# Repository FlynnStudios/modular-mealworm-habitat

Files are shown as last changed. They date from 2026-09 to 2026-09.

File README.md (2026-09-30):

# Modular Mealworm Habitat

A 3D-printed drawer system for keeping a small mealworm colony in a compact, expandable setup.

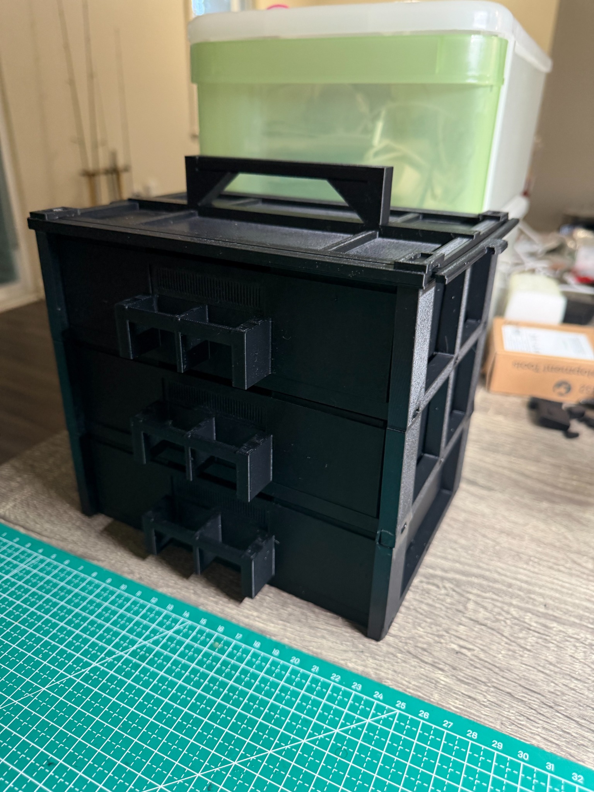
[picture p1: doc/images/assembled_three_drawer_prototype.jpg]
Assembled three-drawer prototype


## Why I Built It

I originally kept mealworms in ordinary food containers. They were convenient, but my ventilation arrangement prevented me from using their stacking features, so the containers occupied more desk space. Their transparent walls also left the insects visible to everyone nearby.

I designed an opaque, three-drawer habitat to separate beetles, small larvae, and larger larvae. Independently removable drawers provide access for routine care, while side vents allow the drawers to remain stacked. Replaceable vent inserts let me revise or replace a failed insert without reprinting the drawer.

## Scope and Status

V1 focuses on a usable basic habitat and a modular frame that can accept additional tiers. Printing time, material use, and structural optimization are planned for later iterations; sensing and automation are longer-term possibilities.

**The three-tier prototype is printed and assembled, and initial use has begun.** Parts were printed in PETG HF on a Bambu P1S with a 0.4 mm nozzle.

- Initial checks confirmed independent drawer access, vent fit, frame assembly, and manual cover installation and removal.
- Occasional drawer realignment remains. Containment, airflow, fourth-tier expansion, loaded carrying, and long-term durability still need verification.

The validation reports distinguish observed results from checks that remain open.

## Repository Guide

| File or folder | Contents |
| --- | --- |
| [Design requirements](design-requirements.md) | Product definition, requirement IDs, and verification criteria. |
| [Development logic](logic.md) | My design workflow and reflections. |
| [Working with AI](thoughts.md) | My experience using AI for test models, design changes, and iteration. |
| [Validation reports](doc/test-logs/) | Test parameters, observations, design decisions, and unresolved checks, linked to requirement IDs. |
| [Build guide](doc/build.md) | File quantities, printing notes, assembly, and the prototype configuration. |
| [CAD source](models/cad/) | Editable OpenSCAD models, organized by component. |
| [Current STL files](models/stl/current/) | Selected drawer, rack, cover, vent, and rear-stop models. |
| [Experimental STL files](models/stl/experiments/) | Fit coupons and earlier variants retained to document iteration. |
| [Photos](doc/images/) | Printed parts, assembly details, and the prototype. |

To review the project, start with the requirements, then the development logic and validation reports. To reproduce the parts, start with the build guide and current STL files.

## Authorship and License

I developed and tested this project with AI assistance for CAD generation and documentation. Requirements, design decisions, and physical evaluation were guided by my own use and observations.

A license has not yet been selected.

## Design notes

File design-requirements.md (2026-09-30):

# V1 Product Requirements

My goal for V1 is a compact, opaque, modular habitat for a small mealworm colony. The starting point is three independent drawers for beetles, small larvae, and larger larvae, with roles reassigned as the colony develops. The system must support routine care and later tier expansion.

V1 prioritizes usable functionality and reliable assembly. Print-time and material optimization, sensing, and automation are reserved for later development.

This document defines design inputs and planned verification. Detailed geometry, connection types, manufacturing settings, and test results are recorded separately.

## 1. Requirement Index

| ID | Requirement | User need | V1 target | Verification |
| --- | --- | --- | --- | --- |
| REQ-01 | Independent drawer access | Manage life stages and perform routine care separately | Three compartments; access one without removing the others | Operation demonstration |
| REQ-02 | Compact desktop footprint | Reduce the space occupied by separately arranged containers | Less occupied desktop area than the existing three-container setup | Dimensional comparison |
| REQ-03 | Ventilation and serviceability | Maintain ventilation when stacked; replace ventilation components independently | Open ventilation paths during closed use; replacement without replacing the drawer | Inspection and replacement trial |
| REQ-04 | Occupant containment | Keep larvae and beetles in their assigned compartments | No escape or transfer between drawers during the defined observation period | Containment observation |
| REQ-05 | Tier expansion | Increase capacity as the colony grows | Add one tier while reusing existing tiers; retain stability and access | Expansion assembly and load test |
| REQ-06 | Removable top cover and carrying handle | Access the upper tier and move the assembled system | Hand-removable cover; secure handling of the loaded three-tier assembly | Removal and carrying tests |
| REQ-07 | Rearward drawer retention | Prevent a drawer from being pushed out of the rear | A seated drawer remains supported during normal insertion | Repeated insertion test |
| REQ-08 | Drawer support and alignment | Insert and withdraw drawers without slipping or jamming | Supported, aligned travel without manual sideways correction | Loaded operation test |
| REQ-09 | Fabrication with available equipment | Build the system using existing printing equipment | Printable components and assembly without specialized equipment | Slicing review and prototype build |

All nine requirements are within V1 scope. IDs provide stable references; their sequence does not indicate implementation order. Verification results are tracked in the test records.

## 2. Requirement Definitions and Checks

### REQ-01 — Independent drawer access

**Requirement:** The system shall provide three separate rearing compartments. Each drawer shall be removable and reinsertable for feeding, inspection, transfer, and cleaning while the other drawers remain installed.

**Verification:** Demonstrate each operation on every tier. Confirm that access does not require dismantling the rack or removing another drawer.

### REQ-02 — Compact desktop footprint

**Requirement:** In its normal closed configuration, the system shall occupy less desktop area than the existing three containers arranged separately for use.

**Verification:** Compare occupied areas using a consistent measurement boundary and ventilation clearance. Record temporary drawer-access space separately.

### REQ-03 — Ventilation and serviceability

**Requirement:** Each compartment shall have a ventilation path available with all drawers closed and stacked. Ventilation components shall be replaceable without replacing or damaging the drawer body.

**Verification:** Inspect every tier for obstructed openings and repeat component replacement. Confirm secure retention and absence of damage. Opening inspection establishes the availability of a ventilation path; suitability during rearing remains part of the use evaluation.

### REQ-04 — Occupant containment

**Requirement:** The closed system shall retain the intended larvae and beetles within their assigned drawers, including the smallest larvae intended for this system.

**Verification:** Observe a populated assembly inside a secondary enclosure. Record life stages, approximate sizes, conditions, and duration. Acceptance requires no escape or unintended movement between compartments within that test period.

### REQ-05 — Tier expansion

**Requirement:** The system shall accept at least one additional tier without remaking the existing tiers. The expanded assembly shall remain stable under its intended load and preserve independent drawer access.

**Verification:** Assemble a fourth tier, apply a recorded representative load, and operate each drawer. Check for connection separation, instability, interference, and damage. This test establishes four-tier capability only.

### REQ-06 — Removable top cover and carrying handle

**Requirement:** The top cover shall remain secured during routine operation and be removable by hand for access and expansion. Its handle and attachment shall support moving the three-tier assembly at its defined service load.

**Verification:** Repeat cover installation and removal, then perform a controlled carrying test using an inert load representing the intended filled assembly. Acceptance requires no release, cracking, or permanent deformation that impairs function. Expanded-stack carrying requires a separate load case.

### REQ-07 — Rearward drawer retention

**Requirement:** Normal insertion shall not push a drawer beyond its supported rear position or allow it to exit through the back of the rack.

**Verification:** Repeatedly seat each loaded drawer and inspect its final position and support. Confirm that rearward travel control remains effective without prescribing a particular stopping mechanism.

### REQ-08 — Drawer support and alignment

**Requirement:** Each drawer shall remain supported and aligned throughout normal insertion and withdrawal, until intentionally removed. It shall not slip sideways or jam in a way that requires manual realignment.

**Verification:** Operate loaded drawers on every tier. Record sideways displacement, jams, manual corrections, and visible damage. Acceptance requires completion of the defined cycles without these functional failures.

### REQ-09 — Fabrication with available equipment

**Requirement:** Custom components shall be printable on the available Bambu P1S with a 0.4 mm nozzle and assemblable without specialized equipment. V1 shall establish a reproducible build process; no fixed print-time or material-mass limit is assigned.

**Verification:** Review build-volume fit, print the components, and assemble the system. Record material, settings, orientation, supports, finishing, and assembly steps. Record time and material use as a baseline, distinguishing slicer estimates from measurements.

## 3. Test Log Plan

Dedicated logs cover tests that require repeated operation, load testing, biological observation, or comparison across revisions. Requirements sharing a setup are recorded together.

| Planned log | Related requirements | Record focus |
| --- | --- | --- |
| Ventilation and component replacement | REQ-03, REQ-09 | Opening availability, replacement cycles, retention, damage, and relevant print conditions |
| Occupant containment | REQ-04 | Life stages, sizes, escape paths, observation conditions, duration, and outcome |
| Modular assembly and expansion | REQ-05 | Assembly method, connection behavior, load, stability, and drawer access after expansion |
| Top cover and carrying handle | REQ-06 | Removal cycles, retention, total carried mass, lifting method, and structural condition |
| Drawer operation and retention | REQ-01, REQ-07, REQ-08 | Independent access, support, alignment, rearward travel, and operating failures |

REQ-02 is recorded as a short footprint comparison in the assembly record. REQ-09 is covered by a complete build record and the relevant component trials; it does not require a duplicate standalone test report.

Each log identifies the REQs, tested revision, setup, acceptance criteria, results, evidence, and follow-up action. Cycle counts, service loads, and observation durations remain open test-planning parameters here and are fixed in the relevant protocol before testing. These planned checks do not indicate that a requirement has passed.

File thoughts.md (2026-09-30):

# My Experience Working with AI

In this project, I wanted to build a mealworm habitat and see how far I could go with AI-assisted design. During development, I realized that some changes would be faster to make myself. I still continued with AI because I wanted to understand where it worked well and where it needed more guidance.

## What Worked Well

AI was useful for generating small test models with different parameters. For example, before printing the full frame, I could print several connection samples and compare their fit. This helped me find problems before spending more time and material on larger parts.

I also think AI can help people who have less experience with testing and version management. It suggested testing individual features, keeping previous versions, and recording the results. It could quickly provide several options for comparison, but I still needed to print and test them to decide which one worked.

## What Took More Time Than Expected

The C connection was one example. After testing its fit, I expected AI to keep the confirmed dimensions and use that connection as the basis for the frame and tier connections. I understood that a different application might need another check, but the result we already had should not be lost.

However, AI sometimes introduced a different arrangement or added separate locking pieces. My intention was to put the pegs directly on the crossbars and the sockets in the side frames. At the same time, I was considering how to assemble the parts and place them on the print bed. AI did not consistently include all of these points without further instructions.

I had to explain the same requirements several times. Clearer prompts helped, but part of the conversation was only correcting its understanding. This used extra time and tokens, and it was especially frustrating when usage was limited.

Once I knew exactly what needed to change, directly editing the CAD model was faster than explaining it again and checking whether AI had changed anything else. I noticed this during the project, particularly for small changes to details that had already been tested.

## What I Would Change Next Time

I would still use AI for initial ideas and test models with different parameters. For integration and small CAD changes, I would do more of the work directly once the design was clear.

I would also try giving AI a short record of confirmed dimensions, tested connections, and what could be changed. I want to see whether this reduces repeated explanations.

This is my experience from one project. I would need to try other models, platforms, and tools before making a broader judgment. I also have not tested whether a higher subscription level would solve these problems.

---

**Reflection recorded:** 2026-09-30 EDT (UTC-04:00).

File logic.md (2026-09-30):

# Product Development Logic

My process starts with a practical need. I define the product, carry out desk research, and work through the requirements with small prototypes and repeated tests.

## Development Process

```mermaid
flowchart TD
    A["Product definition and desk research"] --> B["Requirements and REQ IDs"]
    B --> C["Design and trade-offs"]
    C --> D["Minimum viable prototype"]
    D --> E["Testing and records"]
    E -->|"Iterate"| C
    E -->|"Pass"| F["Assembly and functional testing"]
    F -->|"Iterate"| C
    F -->|"Pass"| G["Complete V1.0"]
```

1. **Product definition and desk research.** I start with the problem I want to solve, look into existing approaches, and decide what the first version needs to do.

2. **Requirements and numbering.** I turn the product goals into requirements, assign REQ IDs, and define how to check them. The IDs connect related work; they do not determine the order of development.

3. **Design and trade-offs.** I compare possible solutions and consider what each adds in function, complexity, time, and cost before choosing an approach.

4. **Minimum viable prototyping.** I test key features before committing to a complete model. Each prototype answers a specific question and helps me decide the next step.

5. **Testing and iteration.** I record observations, data, and photos, modify the design, and test again. I update the records after each round. Assembly and functional testing check whether the parts work together and meet the requirements.

## Post-design Reflection

> [!NOTE]
> **What I want to improve next time**
>
> - **Set clearer test criteria.** I want to decide what counts as a pass before comparing designs.
> - **Check shared dimensions earlier.** I will check how each change affects the parts around it.
> - **Plan assembly checks.** I will make checking one assembled module a regular step before printing more copies.
> - **Give each revision a clear purpose.** I will state what I expect a change to improve, then check whether it does.
> - **Know when to stop.** I will finish the required functions for the current version and leave optional improvements for the next one.

**Reflection recorded:** 2026-09-20 14:31 EDT. **Revised:** 2026-09-29 23:47 EDT (UTC-04:00).

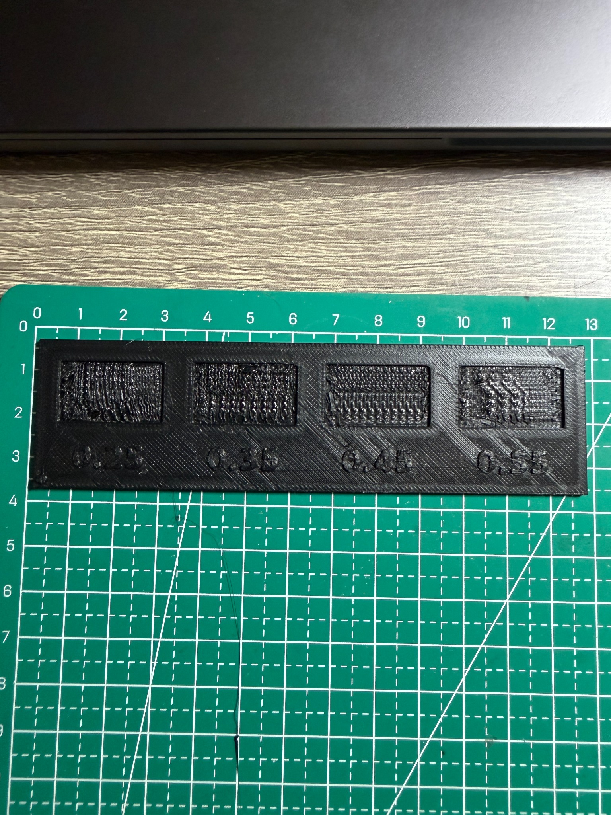
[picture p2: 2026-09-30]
doc/images/vent_coupon_top.jpg

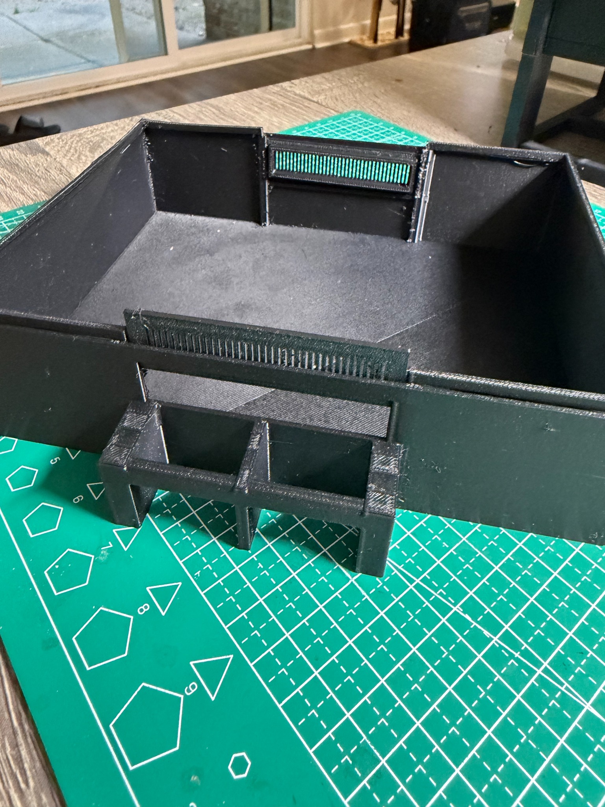
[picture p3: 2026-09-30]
doc/images/drawer_vent_fit.jpg

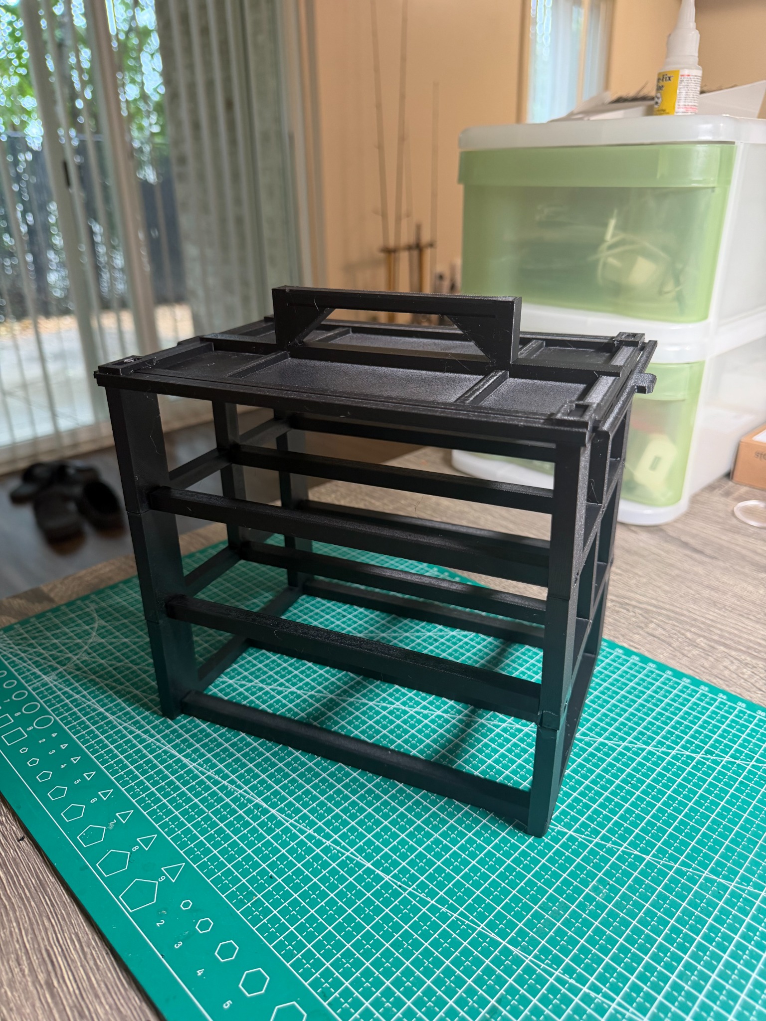
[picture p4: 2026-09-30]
doc/images/empty_three_tier_rack.jpg

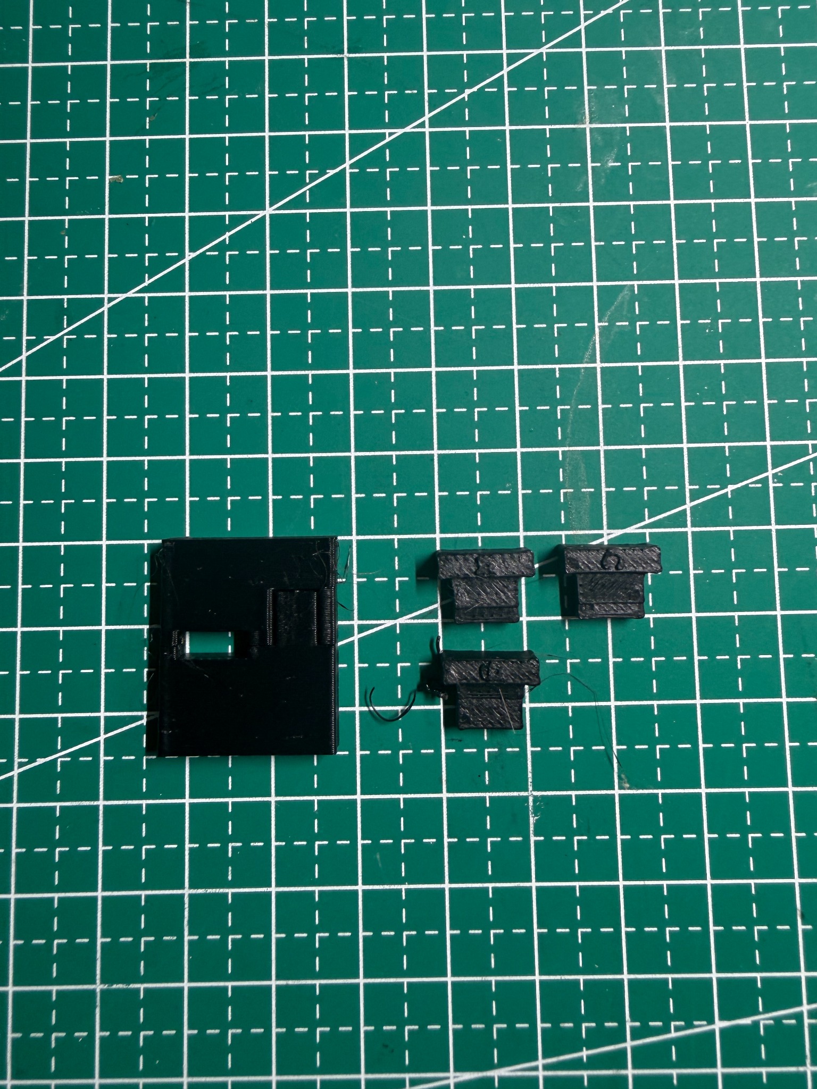
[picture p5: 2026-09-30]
doc/images/joint_fit_coupon.jpg

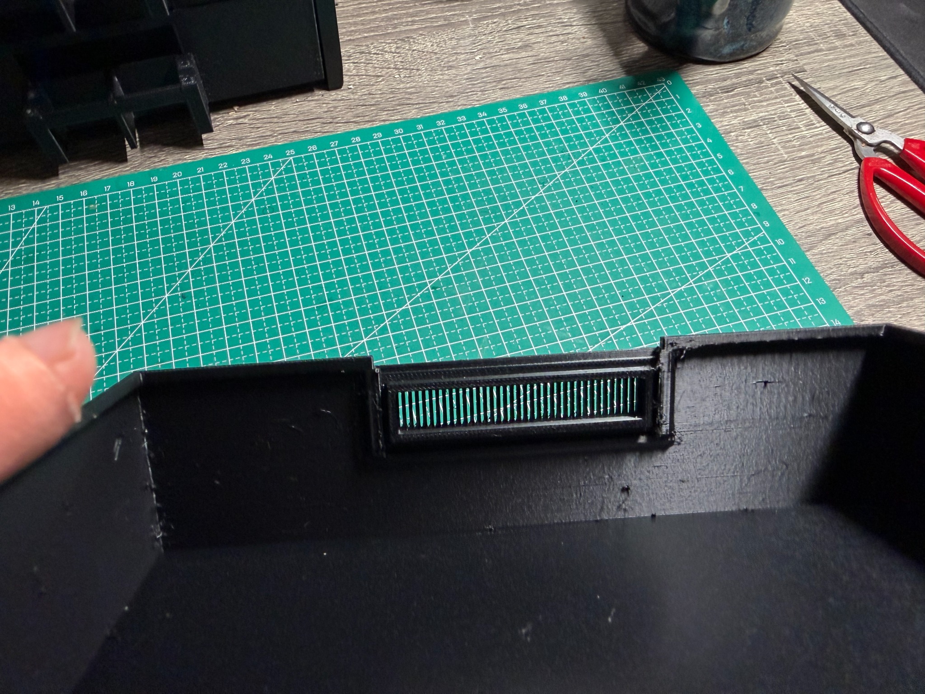
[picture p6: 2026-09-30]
doc/images/vent_receiver_closeup.jpg

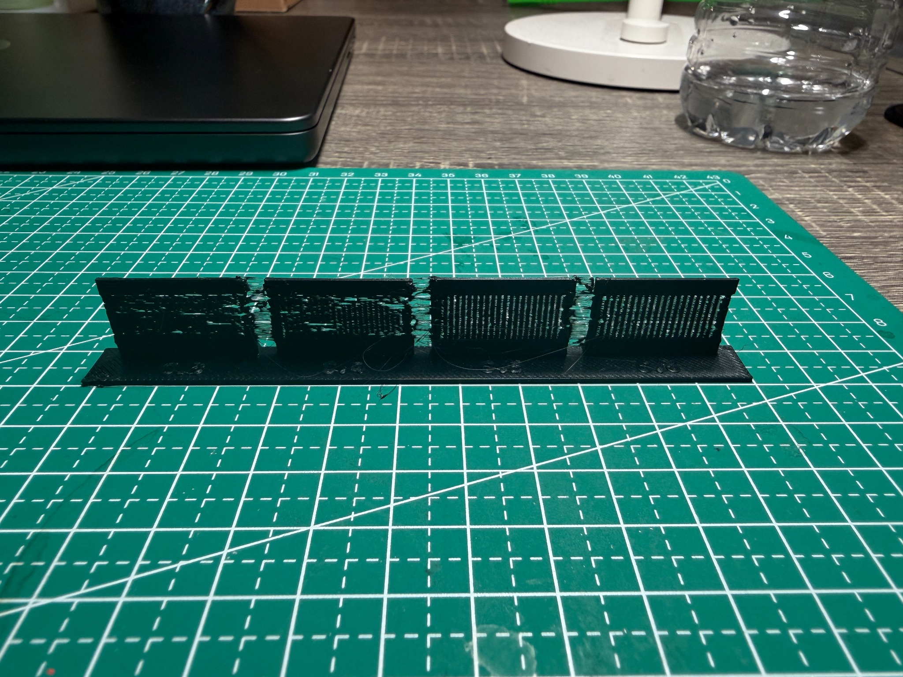
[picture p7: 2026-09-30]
doc/images/vent_coupon_oblique.jpg

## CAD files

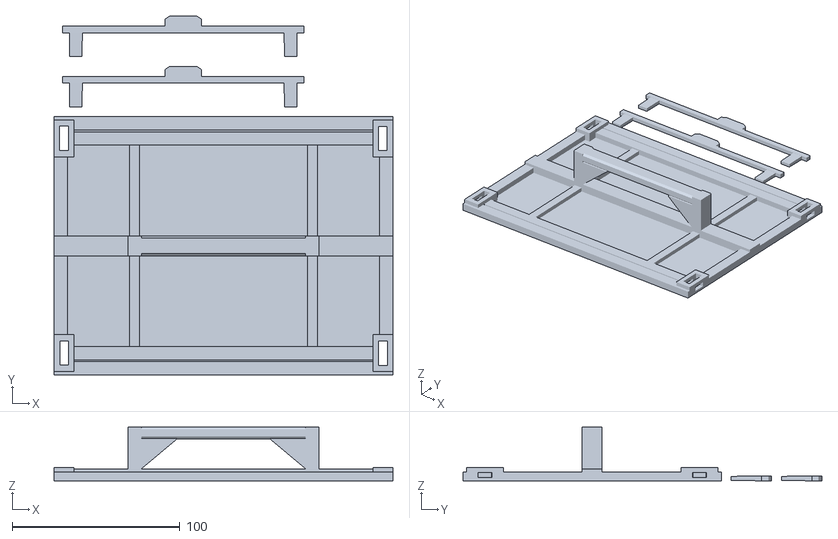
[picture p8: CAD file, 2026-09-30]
models/stl/current/top_cover_carry_v1_1_complete_plate.stl
202.0 x 214.0 x 32.0

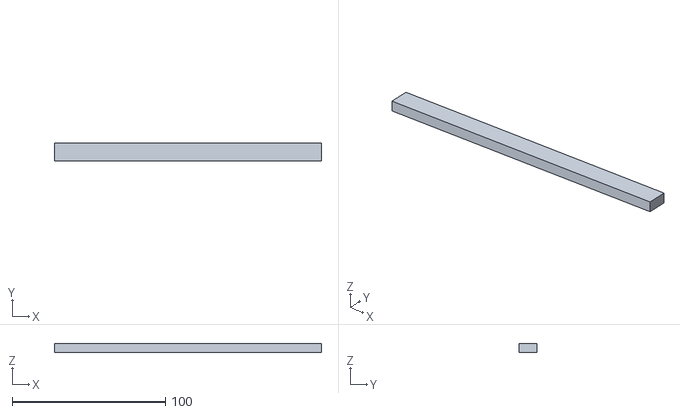
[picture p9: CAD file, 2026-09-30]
models/stl/current/rear_center_glue_stop_r3_5_174x12x6.stl
174.0 x 12.0 x 6.00

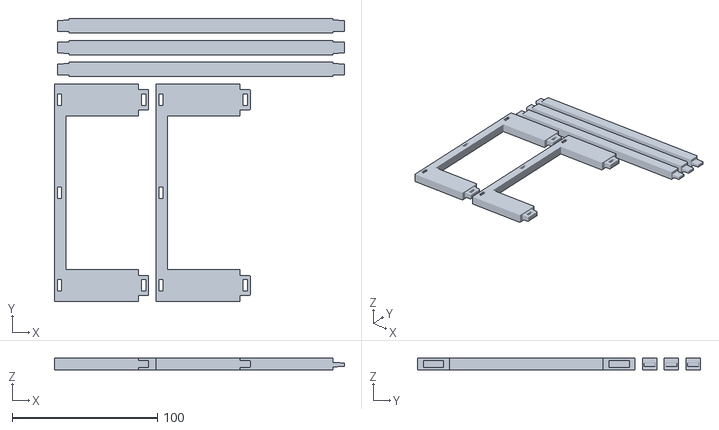
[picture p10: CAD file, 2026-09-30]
models/stl/experiments/rack_flatpack_beam_locked_stack_r3_4_plate.stl
200.0 x 195.0 x 8.00

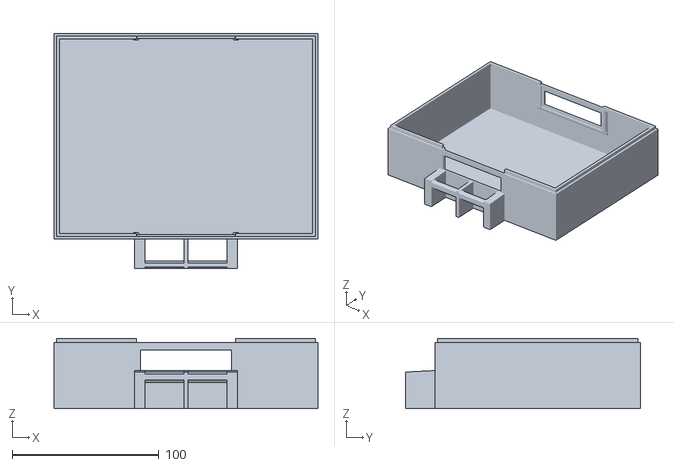
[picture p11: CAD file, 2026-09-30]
models/stl/current/single_drawer_body_v1_4.stl
180.0 x 160.0 x 48.0

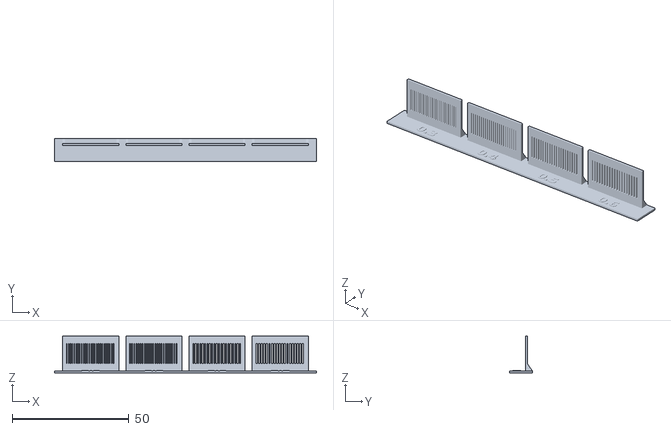
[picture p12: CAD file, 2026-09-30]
models/stl/experiments/vent_slot_calibration_v2_binary.stl
112.0 x 10.0 x 15.8

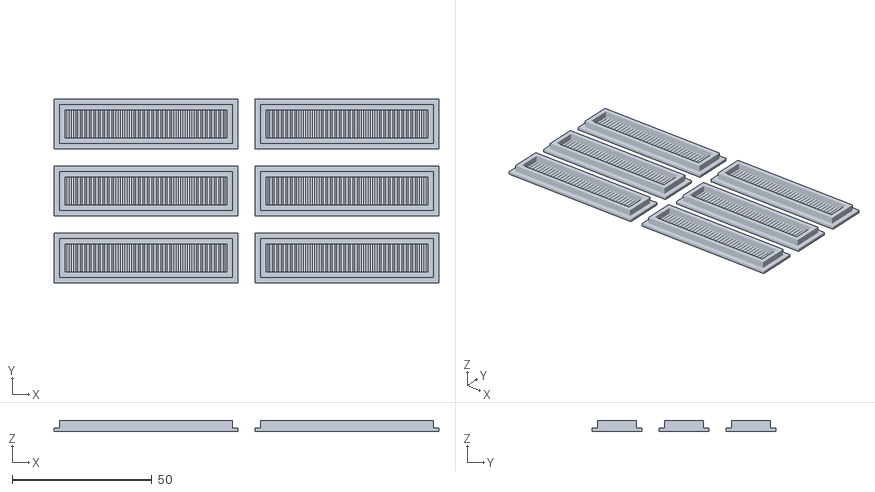
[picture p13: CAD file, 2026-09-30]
models/stl/current/vent_single_060_rib100_x6.stl
138.0 x 66.0 x 4.00

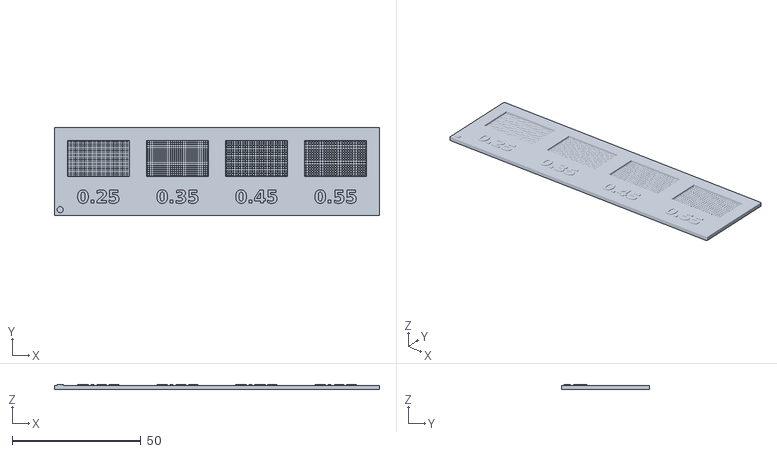
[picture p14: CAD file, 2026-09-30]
models/stl/experiments/vent_mesh_calibration_025_055mm.stl
126.0 x 34.0 x 2.00

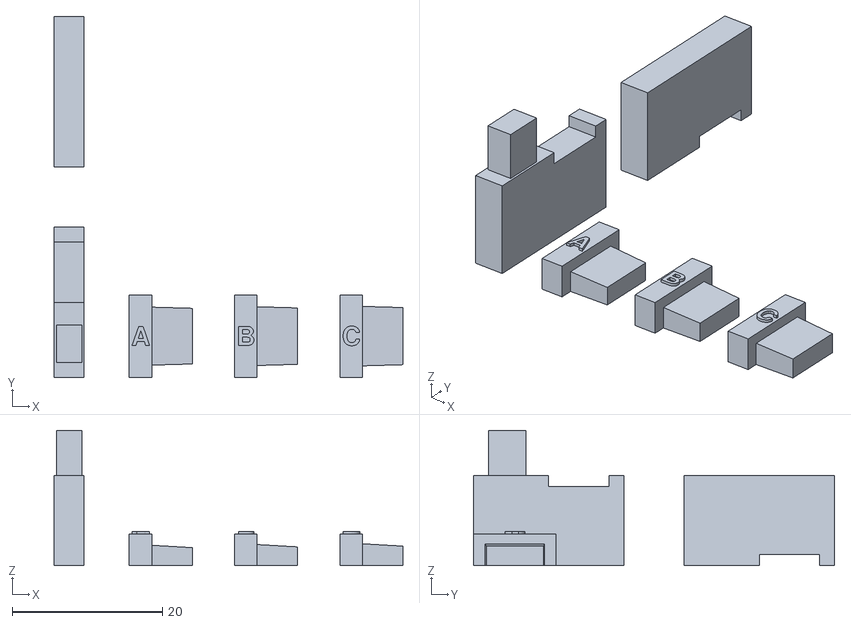
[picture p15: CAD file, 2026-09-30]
models/stl/experiments/joint_lock_fit_test_v2_abc.stl
46.4 x 48.0 x 18.0

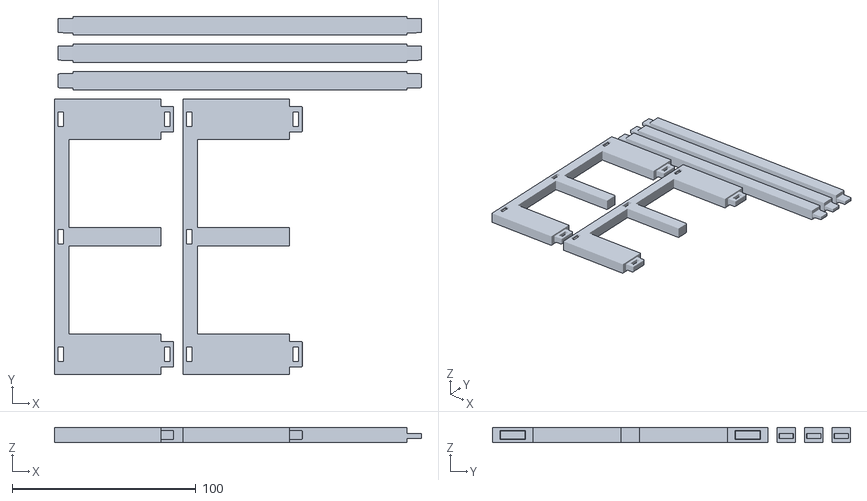
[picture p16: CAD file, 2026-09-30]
models/stl/current/rack_flatpack_center_guide_r3_5_plate.stl
200.0 x 195.0 x 8.00

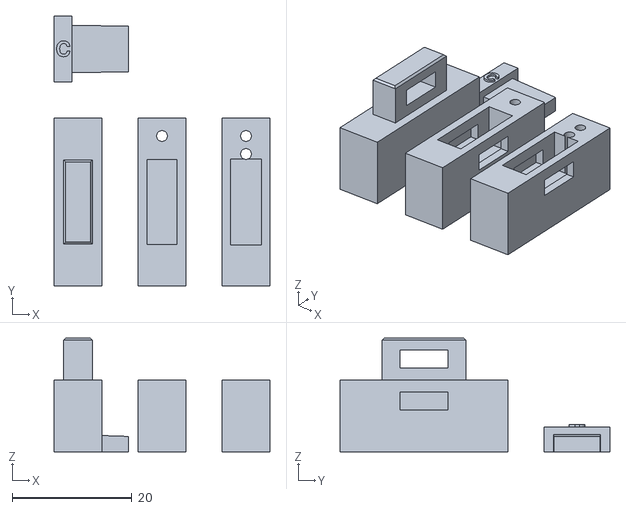
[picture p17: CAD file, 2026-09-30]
models/stl/experiments/captive_joint_fit_test_v3.stl
36.0 x 45.0 x 19.0

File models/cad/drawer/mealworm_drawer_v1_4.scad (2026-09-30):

// Mealworm modular drawer v1.4 — units: mm.
// Target: PETG, 0.4 mm nozzle, 0.20–0.28 mm layer height.
// Export with -D 'part="drawer"|"vent_standard"|"vent_labyrinth"'.
//
// v1.4 corrections after visual review of v1.3:
// - The 70 mm pull becomes a true bridge handle. Fingers enter from below and
//   curl behind a separate chamfered grip bar with 15 mm wall clearance.
// - Two end struts plus one narrow center strut divide the printable bridges.
// - The vent receiver becomes a single tapered U-shaped bezel. Precise capture
//   faces remain, but all exposed shoulders blend back into the drawer wall.
// - The raised inner rim remains 2.2 mm thick and 3.0 mm high; smallest-larva
//   containment has not been tested.
// - The 66 x 4 x 18 mm cartridge envelope and nominal 0.60 mm slots remain.

$fn = 36;
part = "drawer";

// Frozen drawer envelope.
W = 180;
D = 140;
H = 48;
wall = 1.6;
floor_t = 2.4;

// Reinforced raised inner rim.
rim_h = 3.0;
body_h = H-rim_h;
lip_t = 2.2;

// Vent cartridge interface.
vent_open_w = 62;
vent_open_h = 14;
vent_open_z = 26;
module_w = 66;
module_h = 18;
module_z = 24;
module_flange_t = 1.2;
module_depth = 4.0;
slot_w = 0.60;
rib_w = 0.80;

// 70 mm wide bridge handle with a real finger-under clearance.
handle_x0 = 55;
handle_x1 = 125;
handle_bar_front = -20;
handle_bar_rear = -15;
handle_bar_z0 = 18;
handle_bar_z1 = 25;

module grip_bar() {
    // Chamfered 5 x 9 mm grip section. The flat-to-flat dimensions remain
    // comfortable to hook while avoiding a sharp rectangular lower edge.
    polyhedron(
        points=[
            [handle_x0,-19.0,18.0],
            [handle_x0,-16.0,18.0],
            [handle_x0,-15.0,19.2],
            [handle_x0,-15.0,23.2],
            [handle_x0,-16.5,25.0],
            [handle_x0,-19.0,25.0],
            [handle_x0,-20.0,23.6],
            [handle_x0,-20.0,19.4],

            [handle_x1,-19.0,18.0],
            [handle_x1,-16.0,18.0],
            [handle_x1,-15.0,19.2],
            [handle_x1,-15.0,23.2],
            [handle_x1,-16.5,25.0],
            [handle_x1,-19.0,25.0],
            [handle_x1,-20.0,23.6],
            [handle_x1,-20.0,19.4]
        ],
        faces=[
            [7,6,5,4,3,2,1,0],
            [8,9,10,11,12,13,14,15],
            [0,1,9,8],
            [1,2,10,9],
            [2,3,11,10],
            [3,4,12,11],
            [4,5,13,12],
            [5,6,14,13],
            [6,7,15,14],
            [7,0,8,15]
        ], convexity=6
    );
}

module handle_strut(x0,w) {
    // A narrow bed-contacting fin runs from the drawer wall to the grip. The
    // handle therefore does not begin in mid-air even with 15 mm finger space.
    hull() {
        translate([x0,-0.20,0])
            cube([w,0.40,26]);
        translate([x0,handle_bar_front,0])
            cube([w,-handle_bar_front,0.80]);
        translate([x0,handle_bar_front,handle_bar_z0])
            cube([w,handle_bar_rear-handle_bar_front,
                  handle_bar_z1-handle_bar_z0]);
    }
}

module pull_handle() {
    union() {
        grip_bar();
        handle_strut(handle_x0,7);
        handle_strut(88.5,3);
        handle_strut(handle_x1-7,7);
    }
}

// Reinforced receiver geometry.
rail_side_clearance = 0.35;
rail_h = body_h-module_z;
capture_x = 1.20;
retaining_lip_y = 1.20;
flange_channel_clearance = 0.35;
bottom_stop_h = 1.60;
rail_blend_x = 4.20;

module tapered_rail_profile(left_inner,guide_y0,channel_back_y,rail_outer_y) {
    // One continuous printable profile replaces separate guide and lip blocks.
    // The inner faces preserve cartridge clearance; the outer faces form a
    // broad, sloped shoulder that grows naturally from the drawer wall.
    translate([0,0,module_z])
        linear_extrude(height=rail_h)
            polygon(points=[
                [left_inner-rail_blend_x, guide_y0],
                [left_inner-0.70, guide_y0],
                [left_inner, guide_y0+0.50],
                [left_inner, channel_back_y],
                [left_inner+capture_x, channel_back_y],
                [left_inner+capture_x, rail_outer_y-0.30],
                [left_inner+capture_x-0.30, rail_outer_y],
                [left_inner-2.20, rail_outer_y],
                [left_inner-3.20, rail_outer_y-0.80]
            ]);
}

module cartridge_rails_front() {
    x0=(W-module_w)/2;
    left_inner=x0-rail_side_clearance;
    channel_back_y=wall+module_flange_t+flange_channel_clearance;
    rail_outer_y=channel_back_y+retaining_lip_y;
    guide_y0=wall-0.2;
    left_outer=left_inner-rail_blend_x;
    right_outer=W-left_outer;
    bezel_w=right_outer-left_outer;

    union() {
        // Identical tapered side profiles, mirrored about the drawer center.
        tapered_rail_profile(left_inner,guide_y0,channel_back_y,rail_outer_y);
        translate([W,0,0]) mirror([1,0,0])
            tapered_rail_profile(left_inner,guide_y0,channel_back_y,rail_outer_y);

        // One tapered lower sill replaces the former rectangular stop plus
        // separate gusset. Its horizontal top locates the cartridge, while
        // the exposed underside blends continuously back into the wall.
        hull() {
            translate([left_outer,guide_y0,module_z-bottom_stop_h-1.60])
                cube([bezel_w,0.22,bottom_stop_h+1.60]);
            translate([left_outer,channel_back_y-0.50,
                       module_z-bottom_stop_h])
                cube([bezel_w,0.50,bottom_stop_h]);
        }
    }
}

module drawer_shell() {
    union() {
        difference() {
            union() {
                difference() {
                    cube([W,D,body_h]);
                    translate([wall,wall,floor_t])
                        cube([W-2*wall,D-2*wall,body_h-floor_t+0.1]);
                }

                // Reinforced raised inner lip: 2.2 mm thick x 3.0 mm high.
                translate([wall,wall,body_h-0.1])
                    difference() {
                        cube([W-2*wall,D-2*wall,rim_h+0.1]);
                        translate([lip_t,lip_t,-0.05])
                            cube([W-2*(wall+lip_t),D-2*(wall+lip_t),rim_h+0.2]);
                    }

                pull_handle();
            }

            // Standardized front and rear cartridge apertures.
            translate([(W-vent_open_w)/2,-0.05,vent_open_z])
                cube([vent_open_w,wall+0.1,vent_open_h]);
            translate([(W-vent_open_w)/2,D-wall-0.05,vent_open_z])
                cube([vent_open_w,wall+0.1,vent_open_h]);

            // Open the reinforced top rim only over the two cartridge channels.
            // The surrounding rim remains a full 2.2 mm thick.
            translate([(W-module_w)/2-rail_side_clearance-0.25,
                       wall-0.3,body_h-0.2])
                cube([module_w+2*rail_side_clearance+0.5,
                      module_flange_t+flange_channel_clearance+
                      retaining_lip_y+0.6,
                      rim_h+0.4]);
            translate([(W-module_w)/2-rail_side_clearance-0.25,
                       D-wall-module_flange_t-flange_channel_clearance-
                       retaining_lip_y-0.3,
                       body_h-0.2])
                cube([module_w+2*rail_side_clearance+0.5,
                      module_flange_t+flange_channel_clearance+
                      retaining_lip_y+0.6,
                      rim_h+0.4]);
        }

        cartridge_rails_front();
        translate([0,D,0]) mirror([0,1,0]) cartridge_rails_front();
    }
}

module slotted_panel(y0, offset=0) {
    pitch=slot_w+rib_w;
    difference() {
        translate([0,y0,0]) cube([module_w,module_flange_t,module_h]);
        for(x=[2+offset:pitch:module_w-2-slot_w])
            translate([x,y0-0.05,2])
                cube([slot_w,module_flange_t+0.1,module_h-4]);
    }
}

module perimeter_spacer() {
    d=module_depth-module_flange_t+0.1;
    translate([2,module_flange_t-0.1,2]) cube([module_w-4,d,2]);
    translate([2,module_flange_t-0.1,module_h-4]) cube([module_w-4,d,2]);
    translate([2,module_flange_t-0.1,4]) cube([2,d,module_h-8]);
    translate([module_w-4,module_flange_t-0.1,4]) cube([2,d,module_h-8]);
}

module vent_standard() {
    union() {
        slotted_panel(0,0);
        perimeter_spacer();
    }
}

module vent_labyrinth() {
    union() {
        slotted_panel(0,0);
        perimeter_spacer();
        slotted_panel(module_depth-module_flange_t,(slot_w+rib_w)/2);
    }
}

module front_cartridge_assembled() {
    cartridge_y=wall+flange_channel_clearance/2;
    translate([(W-module_w)/2,cartridge_y,module_z]) vent_labyrinth();
}

module fit_check_front_cartridge() {
    intersection() {
        drawer_shell();
        front_cartridge_assembled();
    }
}

module assembly_preview() {
    color([0.68,0.38,0.16]) drawer_shell();
    color([0.00,0.42,0.46]) front_cartridge_assembled();
    color([0.00,0.42,0.46])
        translate([(W-module_w)/2,D-wall-flange_channel_clearance/2,module_z])
            mirror([0,1,0]) vent_labyrinth();
}
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

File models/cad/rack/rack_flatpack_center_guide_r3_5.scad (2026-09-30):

// Flat-pack repeatable rack tier R3.5 — units: mm.
// Target: PETG, 0.4 mm nozzle; actual normal layer height varied by part.
//
// Corrected architecture:
// - Two identical side frames and three identical crossbeams.
// - Every crossbeam has an integral C-spec peg at each end.
// - The front and rear beam pegs also pass through the locating tongues of the
//   tier below, so those four integral pegs lock all four stacking corners.
// - The middle beam supports the drawer and aligns with a slim full-height
//   center guide on each side frame to reduce lateral drawer drift.
// - No loose pins, clips, screws, or extra bottom lock passages.
//
// One print plate contains exactly five parts:
//   2 x identical side frames
//   3 x identical crossbeams with integral C-spec pegs
//
// The C fit comes from joint_lock_fit_test_v2_abc.scad. The tongue/socket fit
// comes from captive_joint_fit_test_v3.scad.

$fn = 40;
part = "print_plate";

// Rack and nominal drawer envelope.
rack_d = 150;
inner_w = 182;               // 180 mm drawer + 1 mm per side.
frame_t = 8;
outer_w = inner_w+2*frame_t;
tier_pitch = 58;

drawer_w = 180;
drawer_d = 140;
drawer_h = 48;
drawer_x = 1;
drawer_y = 0;
drawer_z = 8;

// Two-post side frame and three bottom crossbeams.
rail_h = 8;
post_d = 22;
beam_y = 10;
beam_z = 8;
front_joint_y = post_d/2;             // 11 mm.
middle_beam_y = rack_d/2;             // 75 mm.
rear_joint_y = rack_d-post_d/2;       // 139 mm.
beam_centers = [front_joint_y,middle_beam_y,rear_joint_y];
center_guide_d = 10;          // Slim Y-width; adds guidance without a bulky post.

// One shared transverse centerline lets the front/rear beam pegs double as
// the tier-to-tier locks.
joint_center_z = 3.5;

// Nominal C-spec peg/receiver dimensions.
female_slot_y = 8.0;
female_slot_z = 3.0;
male_root_y = 7.9;
male_root_z = 2.9;
male_tip_reduction = 0.30;
male_len = frame_t;

// Nominal repeatable tongue/socket geometry.
stack_tongue_x = 4.8;
stack_tongue_y = 14.0;
stack_tongue_h = 7.0;
stack_chamfer = 0.35;
stack_clearance = 0.10;      // Per side, selected by the physical test.
stack_socket_extra_depth = 0.20;

module stack_tongue(y_center) {
    tx = (frame_t-stack_tongue_x)/2;
    ty = y_center-stack_tongue_y/2;

    union() {
        translate([tx,ty,tier_pitch-0.10])
            cube([stack_tongue_x,stack_tongue_y,
                  stack_tongue_h-stack_chamfer+0.10]);

        hull() {
            translate([tx,ty,
                       tier_pitch+stack_tongue_h-stack_chamfer-0.01])
                cube([stack_tongue_x,stack_tongue_y,0.02]);
            translate([tx+stack_chamfer,
                       ty+stack_chamfer,
                       tier_pitch+stack_tongue_h-0.02])
                cube([stack_tongue_x-2*stack_chamfer,
                      stack_tongue_y-2*stack_chamfer,0.02]);
        }
    }
}

module stack_socket(y_center) {
    sx = stack_tongue_x+2*stack_clearance;
    sy = stack_tongue_y+2*stack_clearance;
    socket_depth = stack_tongue_h+stack_socket_extra_depth;

    translate([(frame_t-sx)/2,
               y_center-sy/2,
               -0.05])
        cube([sx,sy,socket_depth+0.05]);
}

// All three bottom receivers use the same C slot. At the front and rear this
// one opening is also the layer-lock passage; no second hole is added.
module beam_female_slot(y_center,z_center=joint_center_z) {
    translate([-0.05,
               y_center-female_slot_y/2,
               z_center-female_slot_z/2])
        cube([frame_t+0.10,female_slot_y,female_slot_z]);
}

// Matching passage through the top locating tongue. The next tier's
// front/rear integral beam peg passes through this opening.
module tongue_lock_passage(y_center) {
    translate([-0.05,
               y_center-female_slot_y/2,
               tier_pitch+joint_center_z-female_slot_z/2])
        cube([frame_t+0.10,female_slot_y,female_slot_z]);
}

module side_frame() {
    difference() {
        union() {
            // Continuous lower rail includes the complete bottom support.
            cube([frame_t,rack_d,rail_h]);

            // Two equal corner posts plus one slim central drawer guide.
            cube([frame_t,post_d,tier_pitch]);
            translate([0,rack_d-post_d,0])
                cube([frame_t,post_d,tier_pitch]);
            translate([0,middle_beam_y-center_guide_d/2,0])
                cube([frame_t,center_guide_d,tier_pitch]);

            stack_tongue(front_joint_y);
            stack_tongue(rear_joint_y);
        }

        // Exactly three receiver openings along the bottom rail.
        for (yc=beam_centers)
            beam_female_slot(yc);

        // Two bottom sockets receive the tier below.
        stack_socket(front_joint_y);
        stack_socket(rear_joint_y);

        // Two top-tongue passages are used by the next tier's front/rear
        // beams. They are not an additional bottom-hole system.
        tongue_lock_passage(front_joint_y);
        tongue_lock_passage(rear_joint_y);
    }
}

// Positive-X integral C peg. Its centerline is shared with the tongue hole.
module c_male_peg_positive() {
    tip_y = male_root_y-male_tip_reduction;
    tip_z = male_root_z-male_tip_reduction;

    hull() {
        translate([-0.02,-male_root_y/2,
                   joint_center_z-male_root_z/2])
            cube([0.30,male_root_y,male_root_z]);
        translate([male_len-0.30,-tip_y/2,
                   joint_center_z-tip_z/2])
            cube([0.30,tip_y,tip_z]);
    }
}

module crossbeam() {
    union() {
        translate([0,-beam_y/2,0])
            cube([inner_w,beam_y,beam_z]);

        mirror([1,0,0]) c_male_peg_positive();
        translate([inner_w,0,0]) c_male_peg_positive();
    }
}

module assembled_side_frames(z0=0) {
    translate([0,0,z0]) {
        mirror([1,0,0]) side_frame();
        translate([inner_w,0,0]) side_frame();
    }
}

module assembled_beams(z0=0) {
    translate([0,0,z0])
        for (yc=beam_centers)
            translate([0,yc,0]) crossbeam();
}

module assembled_tier(z0=0) {
    assembled_side_frames(z0);
    assembled_beams(z0);
}

module assembled_frame() {
    assembled_tier(0);
}

module two_tier_stack() {
    assembled_tier(0);
    assembled_tier(tier_pitch);
}

module drawer_body() {
    import("../../stl/current/single_drawer_body_v1_4.stl");
}

module assembled_with_drawer() {
    color([0.34,0.38,0.41]) assembled_frame();
    color([0.78,0.38,0.12,0.82])
        translate([drawer_x,drawer_y,drawer_z]) drawer_body();
}

// Exact two-tier preview: front/rear beams of the upper tier are highlighted
// because their four integral ends are the only layer locks.
module two_tier_preview() {
    color([0.34,0.38,0.41]) {
        assembled_side_frames(0);
        assembled_beams(0);
        assembled_side_frames(tier_pitch);
        translate([0,middle_beam_y,tier_pitch]) crossbeam();
    }

    color([0.82,0.22,0.14]) {
        translate([0,front_joint_y,tier_pitch]) crossbeam();
        translate([0,rear_joint_y,tier_pitch]) crossbeam();
    }

    color([0.82,0.43,0.13,0.42]) {
        translate([drawer_x,drawer_y,drawer_z]) drawer_body();
        translate([drawer_x,drawer_y,tier_pitch+drawer_z]) drawer_body();
    }
}

module side_frame_print(x0) {
    // Broad Y-Z face on the bed; printed height is only 8 mm.
    translate([x0,0,frame_t])
        rotate([0,90,0]) side_frame();
}

module print_plate() {
    side_frame_print(0);
    side_frame_print(70);

    // All three beams are identical. Their end pegs are already fused in.
    for (y0=[160,175,190])
        translate([10,y0,0]) crossbeam();
}

module detail_lower_corner() {
    intersection() {
        mirror([1,0,0]) side_frame();
        translate([-frame_t-0.1,0,tier_pitch-10])
            cube([frame_t+0.2,post_d+2,stack_tongue_h+11]);
    }
}

module detail_upper_corner() {
    translate([0,0,tier_pitch])
        intersection() {
            mirror([1,0,0]) side_frame();
            translate([-frame_t-0.1,0,0])
                cube([frame_t+0.2,post_d+2,12]);
        }
}

module detail_lock_beam() {
    intersection() {
        translate([0,front_joint_y,tier_pitch]) crossbeam();
        translate([-frame_t-0.1,0,tier_pitch-0.1])
            cube([frame_t+34,post_d+2,beam_z+0.2]);
    }
}

// Left/front seam detail. The upper tier beam end passes through the upper
// side-frame receiver and the lower locating tongue at the same time.
module front_left_lock_detail() {
    detail_lower_corner();
    detail_upper_corner();
    detail_lock_beam();
}

// Collision checks return only zero-thickness contact surfaces when correct.
module fit_check_stack() {
    intersection() {
        assembled_tier(0);
        assembled_tier(tier_pitch);
    }
}

module fit_check_drawer() {
    intersection() {
        assembled_frame();
        translate([drawer_x,drawer_y,drawer_z+0.01]) drawer_body();
    }
}
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

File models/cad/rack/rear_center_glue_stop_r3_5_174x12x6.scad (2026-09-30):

// One glued rear-center stop for the three-tier R3.5 rack; units: mm.
// Print orientation lies flat on the bed: 174 x 12 x 6 mm.
// Install orientation is upright: 12 mm across rack, 6 mm rearward, 174 mm tall.
// Glue face rests against the back edge of the three rear crossbeams.
// This replaces the earlier per-tier press-fit bar proposal.

part = "print"; // print | installed

stop_length = 174;
stop_width = 12;
stop_depth = 6;

module rear_stop_print() {
    cube([stop_length,stop_width,stop_depth]);
}

// R3.5 inner frame: X = 0..182; its center is X = 91 mm.
// Rear crossbeams end at Y = 144 mm. Tier bottoms are Z = 0, 58, 116 mm.
module rear_stop_installed() {
    translate([91-stop_width/2,144,0])
        cube([stop_width,stop_depth,stop_length]);
}

if (part == "print") rear_stop_print();
else if (part == "installed") rear_stop_installed();
else assert(false,"Unknown part");

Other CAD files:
models/stl/experiments/single_drawer_body_v1_4_1_rail_foot.stl
models/cad/rack/top_cover_carry_v1_1.scad
models/cad/vent/vent_single_060_rib100_x6.scad

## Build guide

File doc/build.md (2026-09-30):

# Build Guide

This guide covers the three-tier configuration using the files in [models/stl/current](../models/stl/current/). Initial printing and assembly have been checked; functional validation is still in progress.

## 1. Files and Quantities

Print at **100% scale, in millimeters**. The counts below are file copies, not individual parts. Files containing several parts already include their print layout.

| STL file | Copies | Parts produced |
| --- | ---: | --- |
| [single_drawer_body_v1_4.stl](../models/stl/current/single_drawer_body_v1_4.stl) | 3 | Three drawers with integrated finger pulls |
| [rack_flatpack_center_guide_r3_5_plate.stl](../models/stl/current/rack_flatpack_center_guide_r3_5_plate.stl) | 3 | Six side frames and nine crossbars |
| [top_cover_carry_v1_1_complete_plate.stl](../models/stl/current/top_cover_carry_v1_1_complete_plate.stl) | 1 | One cover with integrated handle and two removable side-lock rails |
| [vent_single_060_rib100_x6.stl](../models/stl/current/vent_single_060_rib100_x6.stl) | 1 | Six vent inserts: two per drawer |
| [rear_center_glue_stop_r3_5_174x12x6.stl](../models/stl/current/rear_center_glue_stop_r3_5_174x12x6.stl) | 1 | One rear stop spanning three tiers |

The rack uses the pegs built into the crossbars. It needs no separate rack pins, screws, nuts, or threaded inserts. The **two cover side locks are separate parts** and are included in the cover plate.

Additional material: PETG HF filament and cyanoacrylate adhesive for the rear stop. Purchased mesh is not required.

Component revision numbers are independent of the overall project version. Use the files listed here together; later-looking filenames in `experiments/` are not automatically replacements.

## 2. Printing

**Recorded equipment:** Bambu P1S, 0.4 mm nozzle, PETG HF. Normal layer heights varied between 0.24 and 0.28 mm by part.

| Component | Orientation and support notes |
| --- | --- |
| Drawer | Bottom on the bed, opening upward. Use supports from the build plate for the vent receivers and finger pull. The v1.4 receivers begin above the drawer floor; this file does not include the experimental support feet. |
| Rack plate | Keep the supplied flat layout: side frames lie on their broad faces, with crossbars beside them. Build-plate-only supports were used for the rack. Inspect the small peg undersides and receiver openings in the sliced preview. |
| Cover plate | Flat cover underside on the bed, handle upward; keep both side locks flat beside it. The original support settings were not recorded. Inspect the handle bridge and locking passages before printing. |
| Vent plate | Keep all six inserts flat, slotted face on the bed. Do not generate supports inside the slots. Check that the 0.60 mm nominal slots remain open in the sliced preview. |
| Rear stop | Lay the 174 × 12 mm face on the bed; printed height is 6 mm. |

The exact per-part profiles, first-layer height, temperatures, speeds, wall counts, and infill settings were not retained in the current records. This is not a complete slicer preset. Record these settings when reproducing the build.

Use the **standalone vent file listed above**. The older vent options inside the drawer SCAD are different from the selected six-insert model.

### Recorded slicer estimates

| Component | Quantity | Material | Time |
| --- | ---: | ---: | ---: |
| Supported v1.4 drawer | 1 | 116.78 g | 5 h 40 min |
| Guided R3.5 rack plate | 1 | 62.38 g | 4 h 41 min |
| Cover plate, including both side locks | 1 | 90.12 g | 5 h 15 min |
| Six-insert vent plate | 1 | 13.87 g | 1 h 38 min |
| Rear stop | 1 | 8.24 g | 35 min |
| **Three-tier set: 3 drawers + 3 rack plates + remaining plates** | **1 set** | **649.71 g** | **38 h 31 min** |

The total is calculated from the individual estimates. It is not a measured build time or material total and excludes failed prints, calibration pieces, finishing, and assembly.

## 3. Assembly

Remove supports and loose strings first, especially around the receivers, sockets, and pegs. Check the fit by hand before applying adhesive.

### Rack

Each tier uses two identical side frames and three identical crossbars. The upper tongues and lower sockets locate the tiers. The front and rear crossbar pegs of the tier above pass through the lower tier's tongues and lock the connection.

**Stacking order matters:** align the tongues and sockets before fully seating the crossbars that pass through them. Fully assembled tiers cannot simply be stacked while these pegs occupy the socket passages.

A sequence based on the CAD geometry is:

1. Arrange two columns of three side frames, with the tongues upward and sockets over the tongues below. Support the loose columns during assembly.
2. Position three crossbars at each tier: front, middle, and rear. Start their pegs into one side, then align the opposite side before fully seating the joints.
3. Seat the frame joints progressively. Check that all tier seams close and that the front and rear pegs engage the tongue passages.
4. Test each drawer before adding the cover or rear stop. It should sit on the crossbars with the finger pull facing forward.

Do not force a misaligned peg. Check for support residue and confirm that the tier seams are seated.

[Assembled rack reference](images/empty_three_tier_rack.jpg)

### Vent inserts and rear stop

1. Slide two inserts downward into each drawer's front and rear receivers. The flat slotted face sits toward the drawer wall; the raised spacer faces into the drawer. Seat both inserts without forcing the retaining lips.
2. Stand the rear stop vertically at the center of the rack's back: **174 mm tall, 12 mm wide, 6 mm deep**.
3. Dry-fit it against the rear edges of all three rear crossbars. Check drawer travel, then bond those contact areas with cyanoacrylate and let it cure according to the adhesive instructions.

The rear stop partly obstructs the rear vents. Its current length is specific to three tiers.

[Vent fit reference](images/drawer_vent_fit.jpg)

### Cover

Lower the cover onto the four top tongues. Insert one side-lock rail from each side so that both pins on each rail engage the aligned passages. To remove the cover, withdraw both rails first.

Loaded carrying has not been tested. Support the assembled rack from underneath when moving it until that check is complete.

## 4. Prototype Configuration and Open Checks

The photographed prototype contains **two guided R3.5 tiers and one earlier unguided tier**, plus **two supported v1.4 drawers and one v1.4.1 drawer with receiver support feet**. The print list above instead uses three copies of the current guided frame and supported v1.4 drawer.

Initial assembly, drawer access, and vent fit were checked. Occasional drawer realignment remains. Containment, ventilation during rearing, fourth-tier expansion, loaded carrying, and repeated-use durability remain open.

See the [validation reports](test-logs/) for observations and the [requirements](../design-requirements.md) for the planned checks. For containment testing, use a secondary enclosure as described in the REQ-04 report.

---

**Guide compiled:** 2026-09-30 EDT (UTC-04:00).

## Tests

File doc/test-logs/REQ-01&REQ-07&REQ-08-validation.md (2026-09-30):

# REQ-01 & REQ-07 & REQ-08 Validation Report

**Subject:** Independent drawer access, guidance, and rearward retention.  
**Method:** Manual operation of the assembled three-drawer prototype.

## Checks and Decisions

Dimensions are nominal CAD values. The prototype uses two guided tiers and one earlier unguided tier.

| Check | Parameters | Observation | My decision |
| --- | --- | --- | --- |
| Independent access | Three 180 × 140 × 48 mm drawers; nominal frame opening: 182 mm wide | Each drawer could be removed while the others remained installed | Keep independently removable drawers for routine care. |
| Side guidance | R3.5 center guide: 10 mm front-to-back width | The unguided tier allowed sideways movement and jammed more often. Guides improved insertion, but occasional manual realignment remained | Add a simple center guide to each side frame. |
| Rear retention | One 174 × 12 × 6 mm bar, installed vertically at the rear center and bonded with cyanoacrylate | The bar stopped rearward travel and felt firm under an initial hand push | Use one bar across the three tiers. Accept partial rear-vent obstruction as a current trade-off requiring observation. |
| Finger pull | v1.4: 70 mm span and 15 mm nominal finger clearance | The finger pull printed with supports starting from the build plate | Keep the recessed finger grip and use supports where needed. |

**Slicer estimates:** One supported v1.4 drawer: 116.78 g / 5 h 40 min. Rear bar: 8.24 g / 35 min.

## Conclusion

Independent access and initial rear retention worked in manual use. Drawer guidance improved, but the no-realignment target is not fully demonstrated. Jam frequency, repeated operating cycles, and adhesive durability were not measured.

**Evidence:** [Three-drawer prototype](../images/assembled_three_drawer_prototype.jpg) · [Frame and guides](../images/empty_three_tier_rack.jpg).

---

**Test dates:** Unconfirmed in the retained records.  
**Report compiled:** 2026-09-30 00:03 EDT (UTC-04:00).

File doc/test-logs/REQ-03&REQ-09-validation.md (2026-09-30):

# REQ-03 & REQ-09 Validation Report

**Subject:** Printed ventilation inserts and drawer fit.  
**Method:** Visual inspection and manual installation.  
**Equipment:** Bambu P1S, 0.4 mm nozzle; PETG HF for the final inserts.

## Trials and Decisions

Dimensions below are nominal CAD values, not measured printed openings.

| Trial | Parameters | Observation | My decision |
| --- | --- | --- | --- |
| Flat mesh coupon | Openings: 0.25 / 0.35 / 0.45 / 0.55 mm; ribs: 0.45 mm | Uneven strands and poorly formed openings | Try a thinner upright slot coupon. |
| Upright slot coupon | Slots: 0.30 / 0.40 / 0.50 / 0.60 mm; ribs: 0.50 mm; panel thickness: 0.80 mm | Fine strings remained, but I judged the 0.60 mm section usable | Carry 0.60 mm into the final insert design. |
| Final inserts | 66 × 18 × 4 mm (W × H × D); 0.60 mm slots; 1.00 mm ribs; 1.20 mm face thickness | Six inserts printed and installed, with almost no fine strings and no obvious initial damage | Use replaceable printed inserts to avoid buying mesh and allow separate replacement. |
| Drawer receivers | Two supported v1.4 drawers; one v1.4.1 drawer with support feet extending from Z = 0 to 24 mm | Both arrangements accepted the inserts; supported v1.4 receivers printed acceptably | Keep the supported v1.4 drawers in use; an added support foot was not essential for those prints. |

**Final six-insert plate:** 13.87 g and 1 h 38 min — slicer estimates.

## Conclusion

I selected the final 0.60 mm-slot insert for the assembled prototype. These trials establish initial printability and fit. Repeated replacement and airflow remain unverified; the rear stop partly obstructs the rear vents. Escape prevention is covered separately under REQ-04.

**Evidence:** [Early coupon](../images/vent_coupon_top.jpg) · [Six final inserts](../images/six_vent_print_plate.jpg) · [Drawer fit](../images/drawer_vent_fit.jpg).

---

**First dated print update:** 2026-09-23 20:25 EDT (2026-09-24 00:25 UTC). Later trial dates are unconfirmed.  
**Report compiled:** 2026-09-29 23:56 EDT (UTC-04:00).

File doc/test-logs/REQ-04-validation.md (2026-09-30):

# REQ-04 Validation Report

**Subject:** Larva and beetle containment.  
**Status:** Pending — no recorded containment test.

## Current Configuration and Decision

The dimensions below are nominal CAD values, not measured escape limits.

| Potential escape path | Current configuration | Evidence available |
| --- | --- | --- |
| Vent openings | 0.60 mm-wide × 10 mm-high slots; 1.00 mm ribs | Printability and initial fit were checked. Passage by the smallest intended larvae was not observed in a defined test. |
| Drawer rim | 3.00 mm-high raised rim, 2.20 mm thick; 48 mm total drawer height | The structure was printed. Its containment performance has not been tested. |
| Drawer and cover gaps | Three assembled drawers and a removable top cover | Assembly is complete; actual perimeter gaps and possible routes between drawers have not been systematically checked. |

**My decision:** Retain the current vents and rim as the prototype configuration and evaluate containment separately from printing and assembly. I am not treating nominal slot size as evidence that the smallest larvae cannot pass.

## Next Check

I will observe beetles and the smallest intended larvae in their assigned closed drawers, with the system inside a secondary enclosure. Before starting, I will record the model configuration, life stages, approximate sizes, counts, observation duration, and inspection intervals.

**Pass condition:** No escape or unintended movement between drawers during the recorded observation period. Any observed escape will be traced to its route before I revise the relevant feature.

**Current result:** Not tested. No observation duration or escape count is available.

**Reference:** [Assembled prototype](../images/assembled_three_drawer_prototype.jpg) — configuration evidence only.

---

**Test date:** Not recorded; containment verification pending.  
**Report compiled:** 2026-09-30 00:03 EDT (UTC-04:00).

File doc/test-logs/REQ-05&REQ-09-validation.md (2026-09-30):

# REQ-05 & REQ-09 Validation Report

**Subject:** Frame connections and tier expansion.  
**Method:** Manual fit checks and prototype assembly.  
**Equipment:** Bambu P1S, 0.4 mm nozzle; PETG HF for the final rack.

## Trials and Decisions

Dimensions are nominal CAD values, not measured printed clearances.

| Trial | Parameters | Observation | My decision |
| --- | --- | --- | --- |
| A/B/C pin samples | 8.0 × 3.0 mm hole; A: 7.7 × 2.7, B: 7.8 × 2.8, C: 7.9 × 2.9 mm roots; 5.4 mm shaft length | C fitted, but the two mating blocks still did not engage firmly | Keep the C pin size and continue refining the mating connection. |
| Stacking fit refinement | Selected nominal clearance: 0.10 mm per side | The later sample felt secure and fitted as intended | Use this clearance for the tier tongue/socket interface. |
| Full frame | R3.5: two side frames and three beams per tier; 58 mm tier pitch; integral pegs at both beam ends | Three tiers assembled; fourth-tier expansion was not tested | Integrate the pegs into the beams. The front/rear beam ends also lock the stacking joints, avoiding separate rack pins. |

**Interface distinction:** The final beam peg root is 7.9 × 2.9 mm in an 8.0 × 3.0 mm hole: **0.10 mm total difference per dimension**. The stacking tongue/socket has **0.10 mm clearance per side**. These are separate fits.

**One guided R3.5 tier:** 62.38 g and 4 h 41 min — slicer estimates.

## Conclusion

I selected the tested connection concept for the modular frame. Initial fit and three-tier assembly are established. Fourth-tier expansion, repeated assembly cycles, and load capacity remain unverified.

**Evidence:** [A/B/C samples](../images/joint_fit_coupon.jpg) · [Selected connection](../images/c_joint_selected_assembled.jpg) · [Assembled frame](../images/empty_three_tier_rack.jpg).

---

**Test dates:** Unconfirmed in the retained records.  
**Report compiled:** 2026-09-30 00:03 EDT (UTC-04:00).

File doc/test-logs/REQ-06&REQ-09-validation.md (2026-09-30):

# REQ-06 & REQ-09 Validation Report

**Subject:** Removable top cover and carrying handle.  
**Method:** Manual installation, removal, and ordinary cover handling.  
**Equipment:** Bambu P1S, 0.4 mm nozzle; PETG HF.

## Checks and Decisions

Parameters below describe the v1.1 CAD model; clearances and strength were not instrumentally measured.

| Feature | Parameters | Observation | My decision |
| --- | --- | --- | --- |
| Cover location | 202 × 154 mm cover; two diagonal sockets with 0.15 mm per-side clearance, two with 0.30 mm relief | The cover could be installed and removed by hand | Use light locating friction with extra clearance at two sockets to reduce binding. |
| Cover retention | Two removable side-lock rails engaging four tongue passages | The rails could be fitted and removed by hand | Use positive engagement for retention while keeping the cover removable for expansion. |
| Handle | 114 × 12 × 7 mm grip bar; two 8 mm-wide end supports; 1.20 mm cover skin with reinforcing ribs | No obvious flex during ordinary cover handling; the loaded rack was not lifted | Replace the bulkier concept with two end supports and local reinforcement. |

**Cover, handle, and two side locks:** 90.12 g and 5 h 15 min — slicer estimates.

## Conclusion

I kept the lighter v1.1 cover after the initial fit and handling checks. These checks support printability and manual assembly. They do not establish a carrying load for the complete rack. Loaded lifting and repeated lock/removal cycles remain untested.

**Evidence:** [Assembled prototype](../images/assembled_three_drawer_prototype.jpg).

---

**Test dates:** Unconfirmed in the retained records.  
**Report compiled:** 2026-09-30 00:03 EDT (UTC-04:00).
